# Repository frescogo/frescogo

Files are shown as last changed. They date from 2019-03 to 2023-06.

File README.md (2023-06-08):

<meta http-equiv="Content-Type" content="text/html; charset=UTF-8"/>

# FrescoGO! (v5)

O *FrescoGO!* é um software para avaliação de apresentações de Frescobol
competitivo.
A avaliação é baseada na velocidade que a bolinha atinge a cada golpe dos
atletas.
O *FrescoGO!* oferece dois modos de aferição das velocidades:
- Automático com um radar Doppler que mede as velocidades de pico da bolinha
  continuamente.
- Manual com teclas que medem o intervalo de tempo entre dois golpes
  consecutivos para inferir as velocidades considerando uma distância
  predeterminada entre os atletas.

Links do projeto:
- Site: <https://github.com/frescogo/frescogo>
- E-mail: <go.frescobol@gmail.com>
- Licença: <https://creativecommons.org/publicdomain/mark/1.0/deed.pt_BR>

**O software e a regra do FrescoGO! são de domínio público, podendo ser usados,
  copiados e modificados livremente.**

## Regra

<!--
![Tabela de Pontuação de Golpes](bonus.png)
-->

<p>
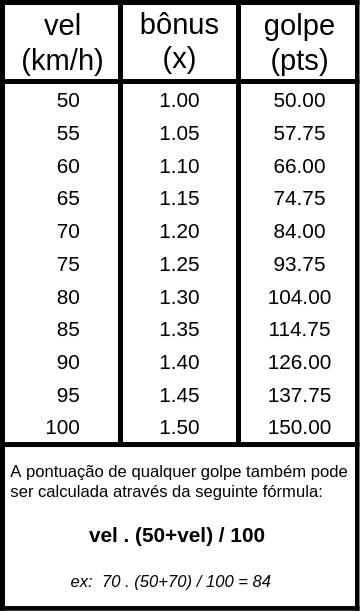
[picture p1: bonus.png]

</p>

- **Tempo**:
    - 6 minutos cronometrados.
- **Quedas**:
   - Cada queda subtrai 12 segundos do tempo corrente.
- **Equilíbrio**:
    - A diferença de pontuação entre os atletas fica limitada a até 30%.
      (Se um atleta pontua 10000, então o outro fica limitado a até 13000.)
- **Golpes**:
   - *Simples*:
        - Cada golpe simples pontua de acordo com a tabela ao lado.
        - São considerados somente os 150 golpes mais fortes de cada atleta.
   - *Contínuos (opcional)*:
        - A cada 10 golpes contínuos, o 5o mais forte deles pontua em dobro.
        - Um golpe contínuo deve suceder em até 1,5 segundo o golpe imediatamente anterior dado do mesmo atleta.
    - *Potentes (opcional)*:
        - Os 25 golpes mais potentes de forehand e de backhand de cada atleta são pontuados em dobro.
        - Um golpe potente deve ser 20% mais forte que o golpe imediatamente anterior.

<!--
- Cada atleta é avaliado em separado com uma pontuação:
    - `ATL = Ata x Vel`
        - `ATL` é a pontuação do atleta a ser calculada.
        - `Ata` é a quantidade de ataques.
        - `Vel` é a média de velocidade dos golpes.
    - São validados somente os `100` ataques mais fortes acima de `50` km/h.
- Cada queda desconta `2%` da pontuação da dupla:
    - `TOTAL = (ATL1 + ATL2) - (2% por queda)`
    - A apresentação é encerrada sumariamente ao atingir `16` quedas.
- Em caso de empate entre duplas, os seguintes quesitos serão usados para
  desempate:
    (1) maior quantidade de golpes,
    (2) menor quantidade de quedas,
    (3) sorteio.
- Resumo:
```
    ATL1  = Ata x Vel
    ATL2  = Ata x Vel
    TOTAL = (ATL1 + ATL2) - (2% por queda)
```
-->

## Agradecimentos

Agradecemos a todos os que contribuíram para o desenvolvimento do FrescoGO!:

- Adão (RJ)
- Alessandra (BA)
- Antônio (RJ)
- Clebinho (RN)
- Dão (RJ)
- Elton (RJ)
- Fátima (RJ)
- Lúcia (RJ)
- Luciano Paredão (RN)
- Luiz Negão (RJ)
- Mateus (RJ)
- PH (RJ)
- Wal (RJ)

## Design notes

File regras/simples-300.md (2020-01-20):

<!--
pandoc simples-300.md -H deeplists.tex -o /tmp/x.pdf
pdftoppm /tmp/x.pdf /tmp/x -png
convert /tmp/x-1.png -trim /tmp/x.png
convert /tmp/x.png -bordercolor White -border 8 simples-300.png
eog simples-300.png
-->

\pagenumbering{gobble}

## FrescoGO! - Regra para 5:00 minutos

Cada atleta é avaliado individualmente em três médias de velocidade:

- Volume:
    média de velocidade de todos os golpes (ataques ou defesas).
- Máximas:
    - Normal:
        média de velocidade dos `24` golpes mais fortes.
    - Revés:
        média de velocidade dos `16` golpes mais fortes de revés.
        - Esse quesito é opcional e pode ser desabilitado.

As três médias constituem a nota de cada atleta com os seguintes pesos:

- `60%` Volume, `25%` Normal, `15%` Revés (quando o revés está habilitado)
- `75%` Volume, `25%` Normal, `0%` Revés (quando o revés está desabilitado)

A pontuação final da dupla será a média entre as notas dos dois atletas.

Caso a nota de um dos atletas esteja muito abaixo da média (margem de `5%`),
então a pontuação final da dupla será essa menor nota.

Cada queda ainda desconta `1%` da pontuação final.
Com 20 quedas, a apresentação é encerrada.

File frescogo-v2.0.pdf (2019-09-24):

## FrescoGO! (versão 2.0)

FrescoGO! é um marcador eletrônico semiautomático para treinamento e competições de Frescobol.

O aparelho marcador contém dois botões de marcação: um para o atleta à esquerda e um para o atleta à direita. A marcação é feita por um juiz, que pressiona o botão correspondente ao atleta toda vez que ele acerta a bola. Com base em uma distância previamente estabelecida e o tempo decorrido entre dois golpes consecutivos, o aparelho calcula a velocidade média atingida pela bola a cada troca. O botão do meio sinaliza início de sequência, queda de bola, fim de apresentação, etc. Também há uma entrada USB para visualização do placar e um saída para som para sinalizar os golpes.

Figure 1: Foto do marcador

- Links do projeto:
- Site: https://github.com/frescogo/frescogo
- E-mail: go.frescobol@gmail.com
- Vídeos: https://www.youtube.com/channel/UCrc_Ds56Bh77CFKXldIU-9g (https://www.youtube.com/channel/UCrc_Ds56Bh77CFKXldIU-9g)
- Licença: https://creativecommons.org/publicdomain/mark/1.0/deed.pt_BR (https://creativecommons.org/publicdomain/mark/1.0/deed.pt_BR)

O projeto eletrônico, o software e a regra são de domínio público, podendo ser usados, copiados e modificados livremente.

Regra de Pontuação

Configuração considerada:

- Tempo: 300s cronometrados (5 minutos)

Quesitos de pontuação:

1

- Atleta:
- Cada atleta é avaliado individualmente pelos seguintes quesitos:
- Volume:
- Média quadrática da velocidade de todos os seus golpes.
- (A média usa as velocidades elevadas ao quadrado.)
- Máximas - Normal:
- Média simples da velocidade dos 24 golpes mais fortes pelo seu lado preferencial (“lado normal”).
- Máximas - Revés:
- Média simples da velocidade dos 12 golpes mais fortes pelo seu lado preferencial (“lado normal”).
- O total do atleta é a média ponderada dos três quesitos:
- ATLETA = (7x Volume + 2x Normal + 1x Revez) / 10
- Equilíbrio:
- A pontuação da dupla será a média de pontos entre os dois atletas.
- Se o atleta que pontuou menos estiver muito abaixo dessa média, então a pontuação da dupla será baseada no menor valor.
- O total da dupla é o menor valor entre a média dos dois e 110% do que pontuou menos:
- EQUILIBRIO = MIN( (A1+A2)/2, MIN(A1,A2)x1.1 )
- Continuidade:
- A apresentação é encerrada sumariamente na 20a queda.
- Os dois últimos golpes antes de cada queda são desconsiderados.
- Cada queda subtrai 2% da pontuação de equilíbrio da dupla:
- TOTAL = EQUILIBRIO x (100 - 2xQUEDAS) / 100

Fluxo da Apresentação

- Um som agudo longo indica que a uma nova apresentação irá começar.
- Um som agudo indica que o atleta pode sacar.
- Após o saque, o juiz pressiona o botão correspondente a cada atleta toda vez que ele acerta a bola. O tempo só passa quando o botão é pressionado.
- Um som identifica a faixa de velocidade do golpe anterior:
- < 40 kmh: som simples grave
- < 50 kmh: som simples médio
- < 60 kmh: som simples agudo
- < 70 kmh: som duplo grave
- < 80 kmh: som duplo médio
- < 90 kmh: som duplo agudo
- >= 90 kmh: som duplo muito agudo
- Um golpe do lado não preferencial do atleta acompanha um som grave (após o som correspondente à velocidade).

2

- Quando a apresentação está desequilibrada, os ataques do atleta que mais pontuou acompanham um som grave.
- Quando a bola cai, o juiz pressiona o botão de queda que emite um som característico.
- Os dois últimos golpes são ignorados e o tempo volta ao momento do último golpe considerado (i.e., um ataque tem que ser defendido e depois confirmado pelo próprio atacante).
- O juiz então pressiona o botão que habilita o saque e o fluxo reinicia.
- Um som agudo é emitido a cada 1 minuto e também quando faltam 30, 10, e 5 segundos para a apresentação terminar.
- A apresentação termina após 5 minutos cronometrados ou após a 20a queda. Um som grave longo indica que a apresentação terminou.
- Ao fim da apresentação, é gerado um relatório com todas as medições de golpes.

Formatação do Resultado

A seguir são explicados os formatos de exibição do resultado da apresentação.

- Placar (a cada sequência)
| Joao / Maria | <-- nome dos atletas
TOTAL | 41.73 pts | <-- total de pontos
Tempo Restante ..... 01:23 | <-- tempo restante
Quedas | 10 | <-- número de quedas
Golpes | 440 | <-- quantidade de golpes
Média | 51 kmh | <-- média geral em km/h
Juiz | Arnaldo | <-- nome do juiz

Joao: 50.27 pts (50.70 vol / 63.87 nrm / 20.08 rev) <-- totais do atleta à esquerda
rev | [ 45 44 40 39 38 35 00 00 00 00 00 00 ... ] | <-- 24 golpes de revés mais fortes
nrm | [ 75 69 67 65 65 65 65 64 64 64 64 64 ... ] | <-- 24 golpes normais | mais fortes

Maria: 54.07 pts (53.39 vol / 64.20 nrm / 38.66 rev) <-- totais do atleta à direita
rev | [ 48 46 41 40 38 38 36 36 36 35 35 35 ... ] | <-- 24 golpes de revés mais fortes
nrm | [ 71 71 67 65 65 64 64 64 64 64 64 64 ... ] | <-- 24 golpes normais | mais fortes

3

v200/750cm/300s/maxs(85,200)/equ1/cont20/fim20) | <-- configurações
\-- versão do software
\-- distância entre os ateltas
\-- tempo máximo de apresentação \-- velocidade máxima a detectar (85 km/h) \-- sensibilidade do revés (200ms)
\-- quesito de equilíbrio (0=desligado, 1=ligado) \-- desconto por queda (20 = 2.0%)
\-- número máximo de quedas

- Relatório (ao final da apresentação)
-- Sequencia | 1 ---------------- | <-- Início da primeira sequência.
**** | <-- Maria efetuou o primeiro golpe.
800 | (33 km/h) | <-- Joao golpeou 800ms depois.
440 | (61 km/h) | A velocidade do primeiro golpe de
820 | (32 km/h) | Maria foi de 33 km/h.
350 | (77 km/h)
790 | (34 km/h)
930 ! | (29 km/h) | <-- Joao golpeou de esquerda (!).
550 | (49 km/h) | <-- Maria golpeou 550ms depois.
610 | (44 km/h) | A velocidade do golpe anterior de
820 | (32 km/h) | Joao foi de 44 km/h.
360 | (75 km/h)
700 | (38 km/h)
370
<-- Queda.
-- Sequencia XX ---------------- | <-- Outras sequências...

Atleta | | | Vol | Nrm | Rev | | | Total | <-- Volume, Normal, Revés e Total
Joao | | | 50.70 | 63.87 | 20.08 | | | 50.27 pts | <-- Pontuação de Joao
Maria | | | 53.39 | 64.20 | 38.66 | | | 54.07 pts | <-- Pontuação de Maria

Media | 52.17 pts | <-- Média entre Joao e Maria
Equilibrio ...... 00.00 (-) | <-- Desconto de equilíbrio
Quedas (10) ..... | 20% (-) | <-- Desconto de quedas
TOTAL | 41.73 pts | <-- Pontuação final da dupla

4

Instruções para o Juiz

Ligação dos Cabos

- Celular (micro USB) -> Aparelho (mini USB)
- É necessário um adaptador micro USB para USB
- Aparelho (PS2/AUX) -> Som (PS2/AUX)

Aparelho marcador:

- Nova apresentação:
- Pressione o botão do meio e em seguida o da direita por 3 segundos.
- Resposta: um som médio de dois segundos.
- Início de sequência:
- Pressione o botão do meio por um segundo, até escutar um som.
- Resposta: um som agudo de meio segundo.
- Golpes dos atletas:
- Pressione o botão da esquerda ou direita quando, respectivamente, o atleta à esquerda ou à direita golpearem a bola. Se o golpe for um revés (lado não preferencial do atleta), o pressionamento deve ser um pouco mais demorado.
- Resposta: depende da velocidade (ver a seção “Fluxo da Apresentação”).
- Queda de bola:
- Pressione o botão do meio por um segundo, até escutar um som.
- Resposta: três sons cada vez mais graves por meio segundo.
- Fim da apresentação:
- Automático, quando o tempo do cronômetro expirar.
- Resposta: um som grave por dois segundos.
- Desfazer última sequência:
- Pressione o botão do meio e em seguida o da esquerda por 3 segundos.
- Resposta: três sons cada vez mais agudos por meio segundo.
- Reconfiguração de fábrica:
- Pressione o botão do meio e em seguida os da esquerda e direita por 3 segundos.
- Resposta: um som médio de dois segundos.
- Em | princípio, | esse | procedimento | nunca | deverá | ser
necessário.

Aplicativo Android

- Instalação (apenas uma vez):
- Instalar o app Serial USB Terminal (by Kai Morich).

5

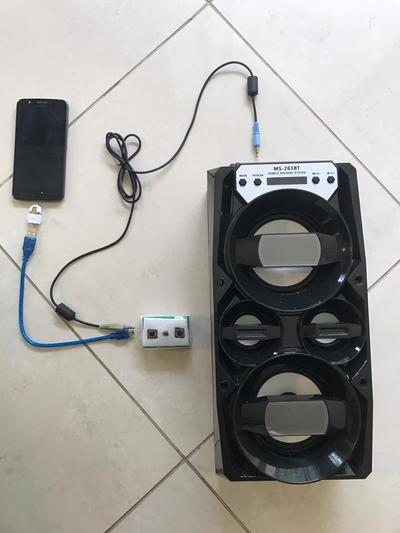
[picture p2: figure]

Figure 2: Ligação dos Cabos

6

- https://play.google.com/store/apps/details?id=de.kai_morich.serial_usb_terminal (https://play.google.com/store/apps/details?id=de.kai_morich.serial_usb_terminal)
- Configuração (apenas uma vez):
- Tocar nas três barras paralelas no canto superior esquerdo e selecionar Settings.
- Trocar Baud rate para 9600.
- Trocar Font size para 10.
- Trocar Font style para Monospace.
- Desabilitar Show timestamps.
- Trocar Buffer size para Unlimited.
- Habilitar Clear input on send.
- Habilitar Keep screen on when connected.

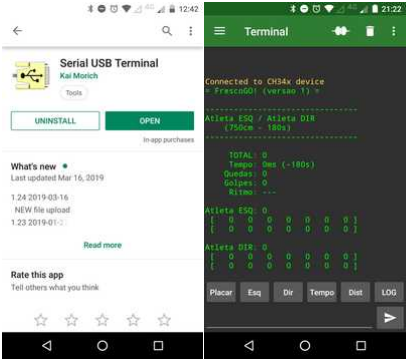
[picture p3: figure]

7

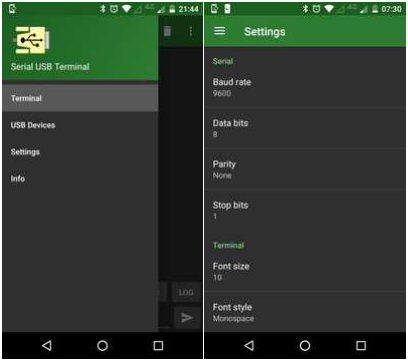
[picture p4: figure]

8

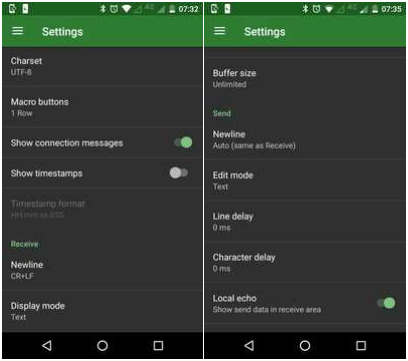
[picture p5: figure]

9

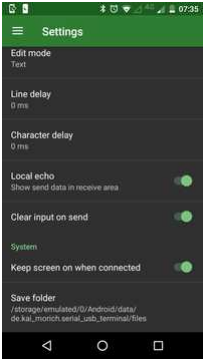
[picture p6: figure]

- Conexão (sempre que abrir o aplicativo):
- Conectar o aparelho ao celular via cabo USB.
- Tocar no ícone com dois cabos desconectados no centro superior direito da tela.
- O ícone deve mudar para um com cabos conectados.
- A área central do app deve exibir Connected to... e o placar da última apresentação.
- Comandos (durante as apresentações):
- Digitar o comando completo na área de texto na base inferior e em seguida tocar no ícone com uma seta no canto inferior direito.
- Exibição:
- placar
- exibe o placar da apresentação
- relatorio
- exibe o relatório completo da apresentação

10

- Ação:
- reiniciar
- reinicia a apresentação imediatamente
- terminar
- termina a apresentação imediatamente
- desfazer
- desconsidera por inteiro a sequência anterior
- restaurar
- restaura a configuração de fábrica
- Configuração da Apresentação:
- tempo SEGS
- altera o tempo total das apresentações para SEGS, que deve ser um número em segundos
- Exemplo:
- tempo 180
- altera o tempo de apresentação para 3 minutos
- distancia CMS
- altera a distância das apresentações para CMS, que deve ser um número em centímetros
- Exemplo:
- distancia 800
- altera a distância para 8 metros
- `maxima VEL`
- altera a velocidade máxima a ser considerada para `VEL`, que deve ser um número em kmh (bolas acima de `VEL` serão consideradas como `VEL`)
- Exemplo:
- `maxima 90`
- bolas acima de 90 kmh serão interpretadas como 90 kmh
- `reves MS`
- altera o tempo mínimo para detectar um revés para `MS`, que deve ser um número em milisegundos
- caso o valor seja `0`, os golpes de revés serão desconsiderados
- Exemplo:
- `reves 200`
- altera a sensibilidade do revés para 200 milisegundos
- `equilibrio SIM/NAO`
- liga ou desliga a pontuação de equlíbrio (`nao=desligada`, `sim=ligada`)
- Exemplo:
- `equilibrio nao`
- desabilita a pontuação de equilibrio
- `esquerda NOME`
- altera o nome do atleta à esquerda para `NOME`, que deve ter até 15 caracteres
- Exemplo:

11

- `esquerda Maria`
- altera o nome do atleta à esquerda para *Maria*
- `direita NOME`
- altera o nome do atleta à direita para `NOME`, que deve ter até 15 caracteres
- Exemplo:
- `direita Joao`
- altera o nome do atleta à direita para *Joao*
- Configuração do Aparelho:
- `juiz NOME`
- altera o nome do juiz para `NOME`, que deve ter até 15 caracteres
- Exemplo:
- `juiz Arnaldo`
- altera o nome do juiz para *Arnaldo*
- `modo MODO`
- altera o modo de exibição para `MODO`, que deve ser `cel` ou `pc`
- Exemplo:
- `modo pc`
- altera o modo de exibição para `pc`
- Envio de relatórios:
- No aplicativo Serial USB Terminal:
- Aguarde o término da apresentação
- Aperte na lata de lixo no canto superior direito para apagar a tela
- Digite relatorio
- Aguarde o término da operação
- Aperte nos 3 pontinhos no canto superior direito
- Selecione Save Data
- Vai aparecer uma mensagem tal como Saved serial_20190602_160522.txt
- No WhatsApp:
- Selecione o contato a enviar o relatório
- Aperte no clipe para anexar um arquivo
- Selecione Documento
- Aperte em Procurar outros documentos...
- Aperte nos 3 pontinhos no canto superior direito
- Selecione Mostrar armazenamento interno
- (Esse procedimento só é necessário uma vez)
- Aperte nas 3 barrinhas no canto superior esquerdo
- Selecione o modelo do seu celular, ex.: Moto E(4)
- Selecione Android
- Selecione data
- Selecione de.kai_morich.serial_usb_terminal
- Selecione files
- Selecione o arquivo a ser anexado, ex.: serial_20190602_160522.txt
- Selecione Enviar

12

- Confirme

Perguntas e Respostas

- Qual é o objetivo desse projeto?
- Oferecer uma maneira objetiva, simples e barata de avaliar apresentações de frescobol.
- Estar disponível no maior número de arenas de frescobol que for possível.
- Auxiliar no desenvolvimento técnico de atletas, estimular a formação de novos atletas e contribuir para o crescimento do Frescobol de competição.
- Como eu consigo um aparelho desses?
- Entre em contato conosco por e-mail:
- go.frescobol@gmail.com
- Esse aparelho é um radar? Como o aparelho mede a velocidade da bola?
- O aparelho não é um radar e mede a velocidade de maneira aproximada:
- Os atletas devem estar a uma distância fixa predeterminada.
- O juiz deve pressionar o botão no momento exato dos golpes (ou o mais próximo possível).
- O aparelho divide a distância pelo tempo entre dois golpes consecutivos para calcular a velocidade.
- Exemplo: se os atletas estão a 8 metros de distância e em um momento a bola leva 1 segundo para se deslocar entre os dois, então a velocidade foi de 8m/s (29 kmh).
- Quais as desvantagens em relação ao radar?
- A principal desvantagem é que a medição não é tão precisa pois os atletas se movimentam e o juiz inevitavelmente irá atrasar ou adiantar as medições.
- OBS.: O radar também não é perfeito, tendo erro estimado entre +1/-2 kmh. Além disso, qualquer angulação entre a trajetória da bola e a posição do radar afeta negativamente as medições (ex., um ângulo de 25 graus diminui as medições em 10%).
- Fonte: https://www.stalkerradar.com/stalker-speed-sensor/faq/stalker-speed-sensor-FAQ.shtml (https://www.stalkerradar.com/stalker-speed-sensor/faq/stalker-speed-sensor-FAQ.shtml)
- Tem alguma vantagem em relação ao radar?
- Custo: Os componentes do aparelho somados custam menos de R$50. O radar custa em torno de US$1000 e não inclui o software para frescobol.
- Licença de uso: Além do custo ser menor, não há nenhuma restrição legal sobre o uso do aparelho, software ou regra por terceiros.
- Infraestrutura: Além do aparelho, é necessário apenas um celular

13 com um software gratuito (para obter o placar das apresentações) e uma caixa de som potente (de preferência com bateria interna). Não é necessário computador, ponto de luz elétrica, área protegida ou outros ajustes finos para a medição da apresentação. Essa simplicidade permite que múltiplas arenas funcionem ao mesmo tempo.
- Transparência das medições: Apesar de serem menos precisas, as medições são audíveis e qualquer erro grosseiro pode ser notado imediatamente. O radar só mede bolas acima de 40 kmh e não é possível identificar se as medições estão sempre corretas (o posicionamento dos atletas, vento e outros fatores externos podem afetar as medições).
- Verificabilidade das medições: Os atletas podem verificar/auditar se a pontuação final foi justa. As apresentações podem ser medidas por um aparelho igual durante as apresentaçõs ou podem ser gravados para medição posterior pelo vídeo.
- Eu posso usar o marcador em competições? Quanto custa? A quem devo pedir permissão?
- Não há nenhuma restrição de uso.
- Não há custos.
- Não é necessário pedir autorização. Não é nem mesmo necessário mencionar o nome do sistema ou autores.
- Como eu posso contribuir?
- Adotando o sistema no dia a dia da sua arena.
- Principalmente com atletas iniciantes.
- Promovendo competições.
- Produzindo vídeos.
- Enviando os relatórios das apresentações para nós.
- Por quê as velocidades são elevadas ao quadrado no quesito de Volume?
- Para incentivar os golpes mais potentes. Quanto maior a velocidade, maior ainda será o quadrado dela. Um golpe a 100 km/h é 2 vezes mais rápido que um a 50 km/h, mas o quadrado de 100 km/h é 4 vezes maior que o de 50 km/h (10000 vs 2500).
- Qual é o objetivo do quesito de Máximas?
- Bonificando os 36 golpes mais velozes pelos dois lados do atleta (12 de revés e 24 normais), a regra incentiva que o atleta ataque acima do seu limite. Os 36 golpes correspondem a mais ou menos 15% dos ataques de um atleta em uma apresentação de 5 minutos.
- Tem como o juiz “roubar”?
- Ao atrasar a marcação de um golpe “A”, consequentemente o golpe “B” seguinte será adiantado. O golpe “A” terá a velocidade reduzida e o golpe “B” terá a velocidade aumentada. Como a regra usa o quadrado das velocidades, esse atraso e adiantamento (se forem sistemáticos) podem afetar a pontuação final.
- Tem como o atleta “roubar” ou “tirar vantagem” da regra?

14

- O atleta pode projetar o corpo para frente e adiantar ao máximo os golpes para aumentar a medição das velocidades.

15

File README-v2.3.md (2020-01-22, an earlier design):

<meta http-equiv="Content-Type" content="text/html; charset=UTF-8"/>

<!--
$ pandoc README.md -H deeplists.tex -o frescogo.pdf
$ pandoc README.md -H deeplists.tex -o frescogo.html
-->

# FrescoGO! (versão 2.3)

*FrescoGO!* é um marcador eletrônico semiautomático para treinamento e
competições de Frescobol.

O aparelho marcador contém dois botões de marcação: um para o atleta à esquerda
e um para o atleta à direita.
A marcação é feita por um juiz, que pressiona o botão correspondente ao atleta
toda vez que ele acerta a bola.
<!--
Golpes de esquerda e direita são distinguidos pelo tempo de pressionamento do
botão.
-->
Com base em uma distância previamente estabelecida e o tempo decorrido entre
dois golpes consecutivos, o aparelho calcula a velocidade média atingida pela
bola a cada troca.
O botão do meio sinaliza início de sequência, queda de bola, fim de
apresentação, etc.
Também há uma entrada USB para visualização do placar e um saída para som para
sinalizar os golpes.

Foto do marcador Foto do Aparelho

- Links do projeto:
    - Site: <https://github.com/frescogo/frescogo>
    - E-mail: <go.frescobol@gmail.com>
    - Vídeos: <https://www.youtube.com/channel/UCrc_Ds56Bh77CFKXldIU-9g>
    - Licença: <https://creativecommons.org/publicdomain/mark/1.0/deed.pt_BR>

**O projeto eletrônico, o software e a regra são de domínio público, podendo
ser usados, copiados e modificados livremente.**

-------------------------------------------------------------------------------

## Regra para 5:00 minutos

- **Golpes:**
    - Cada atleta é avaliado individualmente pelas médias de velocidade dos
      seguintes quesitos:
        - **Volume:**
            - Média *quadrática* da velocidade de todos os seus golpes.
                - (A média quadrática considera as velocidades elevadas ao
                   quadrado.)
        - **Máximas - Normal:**
            - Média simples da velocidade dos `24` golpes mais fortes efetuados
              pelo seu lado preferencial ("lado normal").
        - **Máximas - Revés:**
            - Esse quesito é opcional e pode ser desabilitado.
            - Média simples da velocidade dos `16` golpes mais fortes efetuados
              pelo seu lado não preferencial ("lado revés").
            - O revés só é válido quando supera em 10% a velocidade do golpe
              anterior do parceiro.
    - O total do atleta é a média ponderada entre os quesitos.
        - Revés habilitado:
            - `ATLETA = 60% Volume + 25% Normal + 15% Revés`
        - Revés desabilitado:
            - `ATLETA = 75% Volume + 25% Normal`
- **Equilíbrio:**
    - A pontuação de equilíbrio da dupla é a média entre os totais dos dois
      atletas.
    - Se um atleta estiver abaixo dessa média (com uma margem de 5%), então a
      pontuação de equilíbrio será o menor total:
        - `EQUILIB = MENOR((ATL1+ATL2)/2, MENOR(ATL1,ATL2)x1.05)`
- **Continuidade:**
    - A apresentação é encerrada sumariamente na `20a` queda.
    - Os dois últimos golpes antes de cada queda são sempre desconsiderados.
    - Cada queda subtrai `1%` da pontuação após calcular o equilíbrio da dupla:
        - `FINAL = EQUILIB x (100 - 1x QUEDAS) / 100`

```
  ATLETA  = 60% Volume + 25% Normal + 15% Revés     (75% Volume com o Revés desabilitado)
  EQUILIB = MENOR( (ATLETA1+ATLETA2)/2, MENOR(ATLETA1,ATLETA2)x1.05 )
  FINAL   = EQUILIB x (100 - 1x QUEDAS) / 100
```

Em caso de empate entre duplas, os seguintes quesitos serão usados para
desempate: (1) menor quantidade de quedas, (2) maior quantidade de golpes, (3)
sorteio.

<!--
- 
      Exemplo:
        - Com 5 quedas, a dupla perderá 10% dos pontos, ou seja, se ela pontuou
          4400 após o equilíbrio, a pontuação final será de **3960 pontos**
          (`4400x90%`).
        - Ex., se os atletas pontuaram 4000 e 5000 pontos, pega-se a média
          (`(5000+4000)/2 = 4500`) e 110% do menor (`4000x110% = 4400`).
          A pontuação de equilíbrio será o menor entre os dois valores
          (`4500 vs 4400`): **4400 pontos**.

Os três quesitos são somados As três médias são 

    - A velocidade de cada golpe efetuado por um atleta é elevada ao quadrado,
      dividida por 100 e somada ao total do atleta. Não há velocidade mínima.
      Exemplos:
        - 30 kmh vale **09 pontos**: `30x30/100 =  900/100 =  9`.
        - 40 kmh vale **16 pontos**: `40x40/100 = 1600/100 = 16`.
        - 50 kmh vale **25 pontos**: `50x50/100 = 2500/100 = 25`.
        - 60 kmh vale **36 pontos**: `60x60/100 = 3600/100 = 36`.
        - 70 kmh vale **49 pontos**: `70x70/100 = 4900/100 = 49`.
        - 80 kmh vale **64 pontos**: `80x80/100 = 6400/100 = 64`.
        - 90 kmh vale **81 pontos**: `90x90/100 = 8100/100 = 81`.
- **Máximas:**
    - A média de pontuação dos `36` golpes mais velozes de cada atleta é
      multiplicada por `72` e somada ao seu total (bônus `x2` por cada golpe).
    - São considerados `24` golpes efetuados pelo lado preferencial do atleta
      ("lado normal") e `12` golpes efetuados pelo lado não preferencial do
      atleta ("lado revés").
    - Exemplo:
        - A média dos `24` golpes mais velozes do lado normal foi de `75 kmh`.
        - A média dos `12` golpes mais velozes do lado revés  foi de `55 kmh`.
        - A média dos `36` golpes mais velozes foi então de `68 kmh` com `46`
          pontos por golpe.
        - Esse atleta vai então obter **3312 pontos** (`46 x 72`) no quesito
          de *Máximas* que ainda serão somados aos seus pontos de *Volume*.
    - OBS.:
        - Tipicamente, golpes pelo lado normal são efetuados de *forehand* e
          golpes pelo lado revés de *backhand*. No entanto, qualquer qualidade
          de golpe é válida, inclusive trocando a raquete de mão.
        - Os `36` golpes dentre as máximas também são considerados no quesito
          **Volume** normalmente.
    - OBS.: Em uma apresentação de 3 minutos, 7 golpes correspondem a
      aproximadamente 10% dos golpes em posição de ataque.
-->

-------------------------------------------------------------------------------

## Fluxo da Apresentação

- Um som agudo longo indica que a uma nova apresentação irá começar.
- Um som agudo indica que o atleta pode sacar.
- Após o saque, o juiz pressiona o botão correspondente a cada atleta toda vez
  que ele acerta a bola. O tempo só passa quando o botão é pressionado.
- Um som identifica a faixa de velocidade do golpe anterior:
    - ` < 40 kmh`: som simples grave
    - ` < 50 kmh`: som simples médio
    - ` < 60 kmh`: som simples agudo
    - ` < 70 kmh`: som duplo   grave
    - ` < 80 kmh`: som duplo   médio
    - ` < 90 kmh`: som duplo   agudo
    - `>= 90 kmh`: som duplo   muito agudo
- Um golpe do lado não preferencial do atleta acompanha um som grave (após o
  som correspondente à velocidade).
- Quando a apresentação está desequilibrada, os ataques do atleta que mais
  pontuou acompanham um som grave.
- Quando a bola cai, o juiz pressiona o botão de queda que emite um som
  característico.
- Os dois últimos golpes são ignorados e o tempo volta ao momento do último
  golpe considerado (i.e., um ataque tem que ser defendido e depois confirmado
  pelo próprio atacante).
- O juiz então pressiona o botão que habilita o saque e o fluxo reinicia.
- Um som agudo é emitido a cada 1 minuto e também quando faltam 30, 10, e 5
  segundos para a apresentação terminar.
- A apresentação termina após 5 minutos cronometrados ou após o limite de
  quedas ou após aproximadamente 650 golpes (por restrições técnicas).
  Um som grave longo indica que a apresentação terminou.
- Ao fim da apresentação, é gerado um relatório com todas as medições de
  golpes.

### Formatação do Resultado

A seguir são explicados os formatos de exibição do resultado da apresentação.

- Placar (a cada sequência)

```
-----------------------------------------------
                  Joao / Maria                            <-- nome dos atletas
-----------------------------------------------

TOTAL .............. 41.73 pts                            <-- total de pontos
Tempo Restante ..... 01:23                                <-- tempo restante
Quedas ............. 10                                   <-- número de quedas
Golpes ............. 440                                  <-- quantidade de golpes
Média .............. 51 kmh                               <-- média geral em km/h
Juiz ............... Arnaldo                              <-- nome do juiz

-----------------------------------------------

      Joao: 50.27 pts (50.70 vol / 63.87 nrm / 20.08 rev) <-- totais do atleta à esquerda
 rev  [ 45 44 40 39 38 35 00 00 00 00 00 00 ... ]         <-- 24 golpes de revés mais fortes
 nrm  [ 75 69 67 65 65 65 65 64 64 64 64 64 ... ]         <-- 24 golpes normais  mais fortes

-----------------------------------------------

     Maria: 54.07 pts (53.39 vol / 64.20 nrm / 38.66 rev) <-- totais do atleta à direita
 rev  [ 48 46 41 40 38 38 36 36 36 35 35 35 ... ]         <-- 24 golpes de revés mais fortes
 nrm  [ 71 71 67 65 65 64 64 64 64 64 64 64 ... ]         <-- 24 golpes normais  mais fortes

-----------------------------------------------

v200/750cm/300s/maxs(85,200)/equ1/cont10/fim20)           <-- configurações
  \-- versão do software
       \-- distância entre os ateltas
            \-- tempo máximo de apresentação
                      \-- velocidade máxima a detectar (85 km/h)
                         \-- sensibilidade do revés (200ms)
                              \-- quesito de equilíbrio (0=desligado, 1=ligado)
                                    \-- desconto por queda (10 = 1.0%)
                                           \-- número máximo de quedas

-----------------------------------------------
```

- Relatório (ao final da apresentação)

```
-- Sequencia  1 ----------------        <-- Início da primeira sequência.
            ****                        <-- Maria efetuou o primeiro golpe.
     800            (33 km/h)           <-- Joao golpeou 800ms depois.
             440    (61 km/h)               A velocidade do primeiro golpe de
     820            (32 km/h)               Maria foi de 33 km/h.
             350    (77 km/h)
     790            (34 km/h)
     ...
             930 !  (29 km/h)           <-- Joao golpeou de esquerda (!).
     550            (49 km/h)           <-- Maria golpeou 550ms depois.
             610    (44 km/h)               A velocidade do golpe anterior de
     820            (32 km/h)               Joao foi de 44 km/h.
             360    (75 km/h)
     700            (38 km/h)
             370
                                        <-- Queda.
-- Sequencia XX ----------------        <-- Outras sequências...
...

-----------------------------------------------

    Atleta   |    Vol     Nrm     Rev    |     Total      <-- Volume, Normal, Revés e Total
      Joao   |   50.70   63.87   20.08   |   50.27 pts    <-- Pontuação de Joao
     Maria   |   53.39   64.20   38.66   |   54.07 pts    <-- Pontuação de Maria

-----------------------------------------------

Media ........... 52.17 pts             <-- Média entre Joao e Maria
Equilibrio ...... 00.00 (-)             <-- Desconto de equilíbrio
Quedas (10) .....   10% (-)             <-- Desconto de quedas
TOTAL ........... 46.95 pts             <-- Pontuação final da dupla
```

-------------------------------------------------------------------------------

## Instruções para o Juiz

### Ligação dos Cabos

- Celular (micro USB) -> Aparelho (mini USB)
    - É necessário um adaptador micro USB para USB
- Aparelho (PS2/AUX) -> Som (PS2/AUX)

Ligação dos Cabos

### Aparelho marcador:

- Nova apresentação:
    - Pressione o botão do meio e em seguida o da direita por 3 segundos.
    - Resposta: um som médio de dois segundos.
- Início de sequência:
    - Pressione o botão do meio por um segundo, até escutar um som.
    - Resposta: um som agudo de meio segundo.
- Golpes dos atletas:
    - Pressione o botão da esquerda ou direita quando, respectivamente, o
      atleta à esquerda ou à direita golpearem a bola. Se o golpe for um revés
      (lado não preferencial do atleta), o pressionamento deve ser um pouco
      mais demorado.
    - Resposta: depende da velocidade (ver a seção "Fluxo da Apresentação").
- Queda de bola:
    - Pressione o botão do meio por um segundo, até escutar um som.
    - Resposta: três sons cada vez mais graves por meio segundo.
- Fim da apresentação:
    - Automático, quando o tempo do cronômetro expirar. <!-- ou após a 25a queda. -->
    - Resposta: um som grave por dois segundos.
- Desfazer última sequência:
    - Pressione o botão do meio e em seguida o da esquerda por 3 segundos.
    - Resposta: três sons cada vez mais agudos por meio segundo.
- Reconfiguração de fábrica:
    - Pressione o botão do meio e em seguida os da esquerda e direita por
      3 segundos.
    - Resposta: um som médio de dois segundos.
    - **Em princípio, esse procedimento nunca deverá ser necessário.**

### Aplicativo Android

- Instalação (apenas uma vez):
    - Instalar o app `Serial USB Terminal` (by Kai Morich).
        - <https://play.google.com/store/apps/details?id=de.kai_morich.serial_usb_terminal>

- Configuração (apenas uma vez):
    - Tocar nas três barras paralelas no canto superior esquerdo e selecionar
      `Settings`.
    - Trocar `Baud rate` para `9600`.
    - Trocar `Font size` para `10`.
    - Trocar `Font style` para `Monospace`.
    - Desabilitar `Show timestamps`.
    - Trocar `Buffer size` para `Unlimited`.
    - Habilitar `Clear input on send`.
    - Habilitar `Keep screen on when connected`.

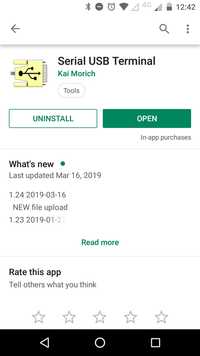
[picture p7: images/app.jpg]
Android App

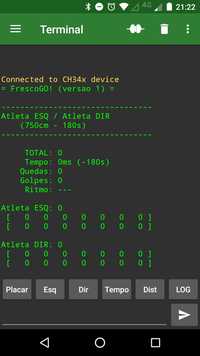
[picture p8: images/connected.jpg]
Conexão USB

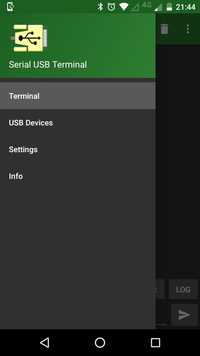
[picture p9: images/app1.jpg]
Configurações Configurações 1/5

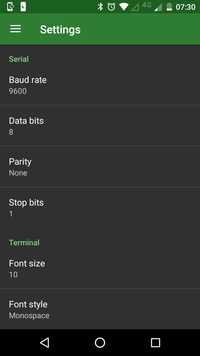
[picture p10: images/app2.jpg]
Configurações Configurações 2/5

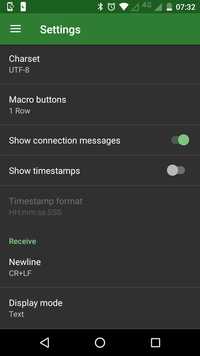
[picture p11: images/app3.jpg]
Configurações Configurações 3/5

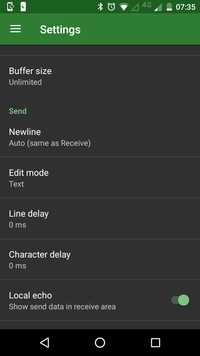
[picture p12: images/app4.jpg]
Configurações Configurações 4/5

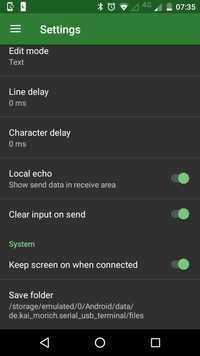
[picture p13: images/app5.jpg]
Configurações Configurações 5/5


- Conexão (sempre que abrir o aplicativo):
    - Conectar o aparelho ao celular via cabo USB.
    - Tocar no ícone com dois cabos desconectados no centro superior direito da
      tela.
        - O ícone deve mudar para um com cabos conectados.
        - A área central do app deve exibir `Connected to...` e o placar da
          última apresentação.

<!--
    - O placar da última apresentação deve ser exibido no centro da tela.
    - A cada queda e reinício, é exibido o placar da apresentação em andamento.
-->

- Comandos (durante as apresentações):
    - Digitar o comando completo na área de texto na base inferior e em seguida
      tocar no ícone com uma seta no canto inferior direito.
    - Exibição:
        - `placar`
            - exibe o placar da apresentação
        - `relatorio`
            - exibe o relatório completo da apresentação
    - Ação:
        - `reiniciar`
            - reinicia a apresentação imediatamente
        - `terminar`
            - termina a apresentação imediatamente
        - `desfazer`
            - desconsidera por inteiro a sequência anterior
        - `restaurar`
            - restaura a configuração de fábrica
    - Configuração da Apresentação:
        - `tempo SEGS`
            - altera o tempo total das apresentações para `SEGS`, que deve ser
              um número em segundos
            - Exemplo:
                - `tempo 180`
                - altera o tempo de apresentação para 3 minutos
        - `distancia CMS`
            - altera a distância das apresentações para `CMS`, que deve ser um
              número em centímetros
            - Exemplo:
                - `distancia 800`
                - altera a distância para 8 metros

<!--
        - `maximas SIM/NAO`
            - liga ou desliga a pontuação de máximas (`nao=desligada`, `sim=ligada`)
            - Exemplo:
                - `maximas sim`
                - habilita a pontuação de máximas
-->

        - `maxima VEL`
            - altera a velocidade máxima a ser considerada para `VEL`, que deve
              ser um número em kmh (bolas acima de `VEL` serão consideradas
              como `VEL`)
            - Exemplo:
                - `maxima 90`
                - bolas acima de 90 kmh serão interpretadas como 90 kmh
        - `reves MS`
            - altera o tempo mínimo para detectar um revés para `MS`, que deve
              ser um número em milisegundos
            - caso o valor seja `0`, os golpes de revés serão desconsiderados
            - Exemplo:
                - `reves 200`
                - altera a sensibilidade do revés para 200 milisegundos
        - `equilibrio SIM/NAO`
            - liga ou desliga a pontuação de equlíbrio (`nao=desligada`, `sim=ligada`)
            - Exemplo:
                - `equilibrio nao`
                - desabilita a pontuação de equilibrio
        - `esquerda NOME`
            - altera o nome do atleta à esquerda para `NOME`, que deve ter até
              15 caracteres
            - Exemplo:
                - `esquerda Maria`
                - altera o nome do atleta à esquerda para *Maria*
        - `direita NOME`
            - altera o nome do atleta à direita para `NOME`, que deve ter até
              15 caracteres
            - Exemplo:
                - `direita Joao`
                - altera o nome do atleta à direita para *Joao*
    - Configuração do Aparelho:
        - `juiz NOME`
            - altera o nome do juiz para `NOME`, que deve ter até 15 caracteres
            - Exemplo:
                - `juiz Arnaldo`
                - altera o nome do juiz para *Arnaldo*
        - `modo MODO`
            - altera o modo de exibição para `MODO`, que deve ser `cel` ou `pc`
            - Exemplo:
                - `modo pc`
                - altera o modo de exibição para `pc`

- Envio de relatórios:
    
    - No aplicativo `Serial USB Terminal`:
        - Aguarde o término da apresentação
        - Aperte na lata de lixo no canto superior direito para apagar a tela
        - Digite `relatorio`
            - Aguarde o término da operação
        - Aperte nos 3 pontinhos no canto superior direito
            - Selecione `Save Data`
                - Vai aparecer uma mensagem tal como `Saved serial_20190602_160522.txt`
    - No `WhatsApp`:
        - Selecione o contato a enviar o relatório
        - Aperte no clipe para anexar um arquivo
            - Selecione `Documento`
        - Aperte em `Procurar outros documentos...`
        - Aperte nos 3 pontinhos no canto superior direito
            - Selecione `Mostrar armazenamento interno`
                - (Esse procedimento só é necessário uma vez)
        - Aperte nas 3 barrinhas no canto superior esquerdo
            - Selecione o modelo do seu celular, ex.: `Moto E(4)`
            - Selecione `Android`
            - Selecione `data`
            - Selecione `de.kai_morich.serial_usb_terminal`
            - Selecione `files`
            - Selecione o arquivo a ser anexado, ex.:  `serial_20190602_160522.txt`
            - Selecione `Enviar`
                - Confirme

<!--
        - `continuidade PCT`
            - altera o percentual de perda por queda de bola para `PCT`, que
              deve ser um número
-->

-------------------------------------------------------------------------------

## Perguntas e Respostas

- Qual é o objetivo desse projeto?
    - Oferecer uma maneira objetiva, simples e barata de avaliar apresentações
      de frescobol.
    - Estar disponível no maior número de arenas de frescobol que for possível.
    - Auxiliar no desenvolvimento técnico de atletas, estimular a formação de
      novos atletas e contribuir para o crescimento do Frescobol de competição.

- Como eu consigo um aparelho desses?
    - Entre em contato conosco por e-mail:
        - <go.frescobol@gmail.com>

- Esse aparelho é um radar? Como o aparelho mede a velocidade da bola?
    - O aparelho não é um radar e mede a velocidade de maneira aproximada:
        - Os atletas devem estar a uma distância fixa predeterminada.
        - O juiz deve pressionar o botão no momento exato dos golpes (ou o mais
          próximo possível).
        - O aparelho divide a distância pelo tempo entre dois golpes
          consecutivos para calcular a velocidade.
        - Exemplo: se os atletas estão a 8 metros de distância e em um momento
          a bola leva 1 segundo para se deslocar entre os dois, então a
          velocidade foi de 8m/s (29 kmh).

- Quais as desvantagens em relação ao radar?
    - A principal desvantagem é que a medição não é tão precisa pois os atletas
      se movimentam e o juiz inevitavelmente irá atrasar ou adiantar as
      medições.
    - OBS.:
      O radar também não é perfeito, tendo erro estimado entre +1/-2 kmh.
      Além disso, qualquer angulação entre a trajetória da bola e a posição do
      radar afeta negativamente as medições (ex., um ângulo de 25 graus diminui
      as medições em 10%).
        - Fonte: <https://www.stalkerradar.com/stalker-speed-sensor/faq/stalker-speed-sensor-FAQ.shtml>

- Tem alguma vantagem em relação ao radar?
    - **Custo**:
        Os componentes do aparelho somados custam menos de R$50.
        O radar custa em torno de US$1000 e não inclui o software para
        frescobol.
    - **Licença de uso**:
        Além do custo ser menor, não há nenhuma restrição legal sobre o uso
        do aparelho, software ou regra por terceiros.
    - **Infraestrutura**:
        Além do aparelho, é necessário apenas um celular com um software
        gratuito (para obter o placar das apresentações) e uma caixa de som
        potente (de preferência com bateria interna).
        Não é necessário computador, ponto de luz elétrica, área protegida ou
        outros ajustes finos para a medição da apresentação.
        Essa simplicidade permite que múltiplas arenas funcionem ao mesmo
        tempo.
    - **Transparência das medições**:
        Apesar de serem menos precisas, as medições são audíveis e qualquer
        erro grosseiro pode ser notado imediatamente.
        O radar só mede bolas acima de 40 kmh e não é possível identificar se
        as medições estão sempre corretas (o posicionamento dos atletas, vento
        e outros fatores externos podem afetar as medições).
    - **Verificabilidade das medições**:
        Os atletas podem verificar/auditar se a pontuação final foi justa.
        As apresentações podem ser medidas por um aparelho igual durante as
        apresentaçõs ou podem ser gravados para medição posterior pelo vídeo.

- Eu posso usar o marcador em competições? Quanto custa? A quem devo pedir
  permissão?
    - Não há nenhuma restrição de uso.
    - Não há custos.
    - Não é necessário pedir autorização.
      Não é nem mesmo necessário mencionar o nome do sistema ou autores.

- Como eu posso contribuir?
    - Adotando o sistema no dia a dia da sua arena.
        - Principalmente com atletas iniciantes.
    - Promovendo competições.
    - Produzindo vídeos.
    - **Enviando os relatórios das apresentações para nós.**

<!--
- Como eu posso contribuir financeiramente?
    -
-->

-------------------------------------------------------------------------------

- Por quê as velocidades são elevadas ao quadrado no quesito de *Volume*?
    - Para incentivar os golpes mais potentes.
      Quanto maior a velocidade, maior ainda será o quadrado dela.
      Um golpe a 100 km/h é 2 vezes mais rápido que um a 50 km/h, mas o
      quadrado de 100 km/h é 4 vezes maior que o de 50 km/h (10000 vs 2500).

- Qual é o objetivo do quesito de *Máximas*?
    - Bonificando os 36 golpes mais velozes pelos dois lados do atleta (12 de
      revés e 24 normais), a regra incentiva que o atleta ataque acima do seu
      limite.
      Os 36 golpes correspondem a mais ou menos 15% dos ataques de um atleta em
      uma apresentação de 5 minutos.

<!--
    - E por quê a regra não considera todos os 7 golpes mais velozes (no lugar
      de considerar apenas o 7o)?
        - Para minimizar a imprecisão da marcação do juiz.
          É possível que o juiz acelere a marcação de alguns golpes, mas é
          pouco provável que isso afete sensivelmente a 7a bola mais veloz.

- Por quê algumas apresentações já iniciam com uma pontuação que eu não consigo
  zerar?
    - Quando a pontuação de Máximas está desligada (`potencia nao`), a regra
      assume um valor fixo de 50 kmh para todos os 7 golpes mais velozes de
      esquerda e de direita **que já são contabilizados no início da
      apresentação**.
    - Isso é feito para evitar os dois modos (ligado e desligado) fiquem com
      pontuações próximas.
-->

- Tem como o juiz "roubar"?
    - Ao atrasar a marcação de um golpe "A", consequentemente o golpe "B"
      seguinte será adiantado.
      O golpe "A" terá a velocidade reduzida e o golpe "B" terá a velocidade
      aumentada.
      Como a regra usa o quadrado das velocidades, esse atraso e adiantamento
      (se forem sistemáticos) podem afetar a pontuação final.

- Tem como o atleta "roubar" ou "tirar vantagem" da regra?
    - O atleta pode projetar o corpo para frente e adiantar ao máximo os golpes
      para aumentar a medição das velocidades.

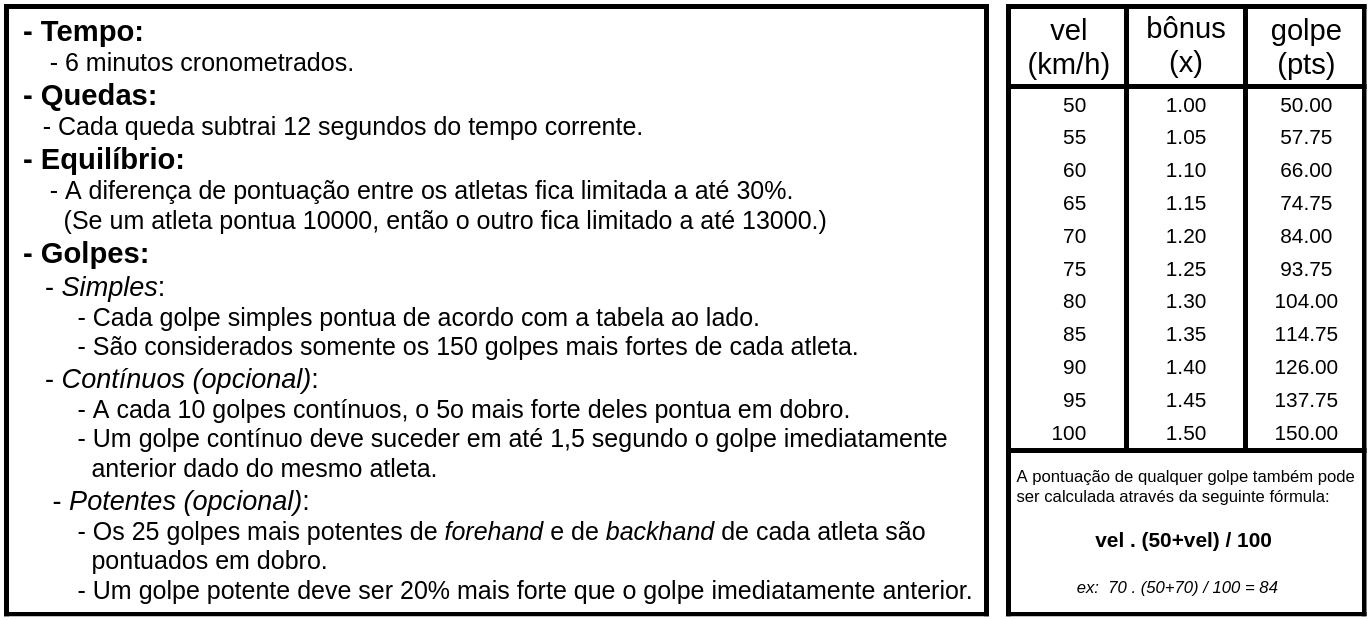
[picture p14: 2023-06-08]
regra.png

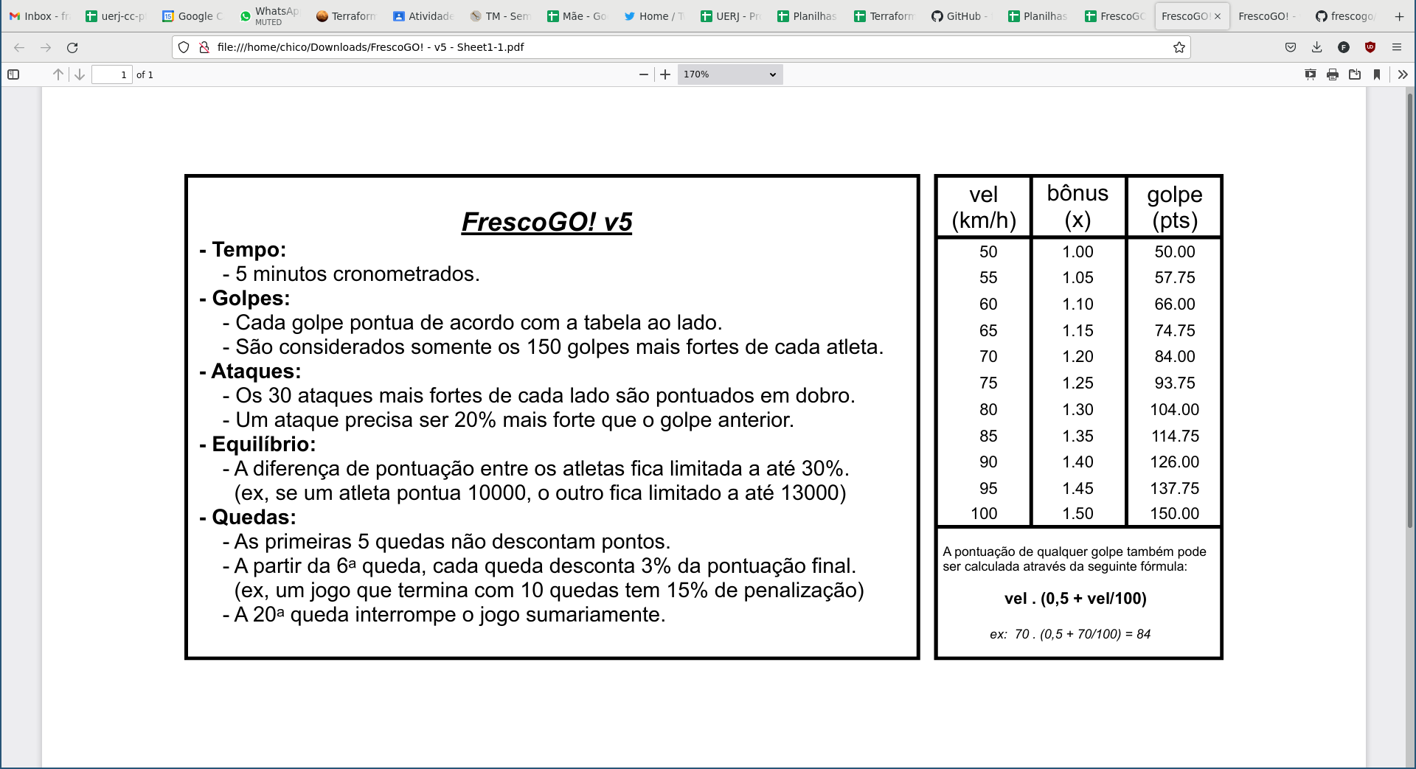
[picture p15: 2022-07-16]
frescogo.png

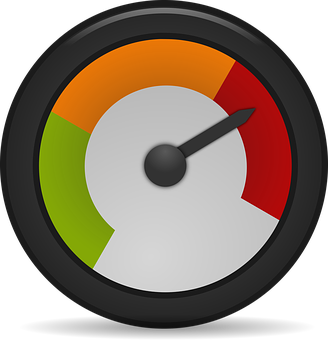
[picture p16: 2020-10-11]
slides/avericao.webp

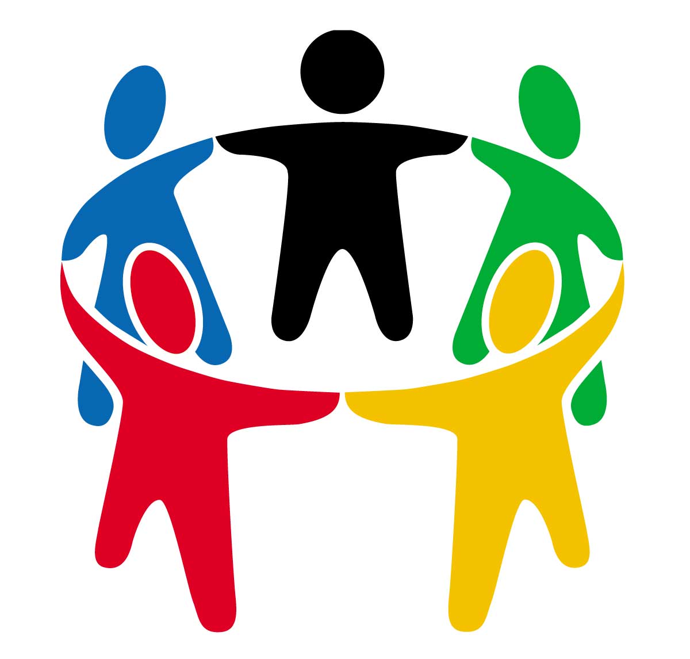
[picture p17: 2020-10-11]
slides/grupo.jpg

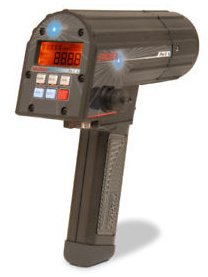
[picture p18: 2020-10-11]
slides/stalker.jpg

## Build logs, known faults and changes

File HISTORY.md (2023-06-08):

v5.4 (jun/23)
-------------

- Nova regra para quedas: remove tempo em vez de pontos.
    - Não há mais limite de 20 quedas.
- Prefixo de categoria para os logs configurável.
- Remove opção da regra v4.

v5.3 (fev/23)
-------------

- Exibe maxs/ints no placar.

v5.2 (out/22)
-------------

- Nova regra de intensidade.
- Pisca tempo a partir de `0:05`, sem decrescer até terminar.
- Renomeia regra de "Ataques" para "Máximas".

v5.1 (ago/22)
-------------

- Timer de teclas 2s para 3s.
- Alternância de regras `CTRL-V` (v4 e v5).
- Som duplo para defesa (no lugar de golpe normal).
- Teclas `Z/M` separadas para esquerda/direita e com tolerância de 500ms.

v5.0 (jul/22)
-------------

- Modo `CTRL-M` de depuração.
- Algumas operações por teclado requerem 3s de pressionamento.
- Regra de ataques dos dois lados (dir/esq).
  - Árbitro pressiona Z ou M para golpe não preferencial, que acompanha um som.
- Nova fórmula de bônus.
- Exibe médias de velocidade ao final do jogo (máx/min, 75+/75-, dir/esq).
- Exibição dos atletas não mais espelhada.
- Relatório foi simplificado.

v4.3 (jan/22)
-------------

- Nova faixa de som acima de 100kmh.
- Toca som ao adicionar/diminuir quedas.
- Aplica desequilibrio paulatinamente entre 0-100s.
- Exibe a soma bruta no placar.
- Limita pontuacao a 300 pontos (equivalente a 100kmh).

v4.2 (dez/21)
-------------

- Mostra o percentual de desequilíbrio.
- Permite voltar bola mesmo após término do jogo.
- Conta golpes manuais no modo radar sempre com a velocidade 30km/h.

v4.1 (nov/21)
-------------

- Fundo vermelho para atleta que está atrás (e não o contrário).
- Som diferente para velocidade >100kmh.
- Corrige backspace que não funcionava na edição dos nomes.
- Nova aferição para evitar duplicatas.
    - Também permite configurar tempo mínimo entre golpes.
- Launcher para Linux.

v4.0 (jun/21)
-------------

- Nova regra.
- Novos sons. Faixas de 10 em 10km/h.
- v4.0.2
    - Nova configuração `RADAR_REPS` para calibre do radar.

v3.1 (ago/20)
-------------

- Suporte ao radar.
- Operação manual pelo teclado.
- Jogo de trincas.
- Máximo de 100 ataques por atleta.
- v3.1.2
    - Modo "esquenta" de aquecimento.
    - Não toca sons abaixo de 50 (mas continua exibindo).
    - Corrige CTRL-BACKSPACE.
- v3.1.3
    - Relatório geral da competição em "resultados.csv".
    - Correções no tempo de aquecimento.
    - Tempo máximo de descanso com contagem regressiva.
    - Som acima de 90 km/h.
    - Tempo passa a cada segundo.
    - Tamanho das fontes maiores.

v3.0 (jul/20)
-------------

- Regra nova com limite de golpes e velocidade mínima de ataque.
- Base: 4 minutos, 50 km/h, 120 ataques (108+12).

v2.4 (fev/20)
-------------

- Padrão de tempo é de 4:00 (era 5:00).
    - 1.5% por queda (1.2% para 5:00).
    - 20 normais (25 para 5:00).
    - 12 revés (15 para 5:00).
- Marca tempo de descanso.
- Aparelho detecta se placar está conectado.
- Acumulativo dá valores comparáveis em qualquer tempo.

v2.3 (jan/20)
-------------

- Envia configuração do aparelho para o placar.
- Move os 15% da pontuação de Revés para o Volume, caso esteja desabilitado.

v2.2 (jan/20)
-------------

- Além da pontuação média, calcula uma pontuação acumulativa.
- Não limita desconto de quedas durante o jogo, somente no fim.

v2.1 (jan/20)
-------------

- Desconto de 1% por queda (era 2%).

v2.0 (out/19)
-------------

- Regra totalmente remodelada.

v1.12 (set/19)
-------------

- A regra passa a usar o jogo de 5 minutos (300 segundos) como referência.
- O quesito de "Máximas" foi remodelado:
    - 36 golpes mais velozes: 24 normais e 12 revés (eram 11 para ambos).
    - Multiplicador de `x2` (era `x3`).
- As Máximas vêm habilitadas, mas sem o revés por padrão.
- O fator de queda passa a ser `2%` (era `1.8%`).
- O máximo de quedas passa a ser `20` (era `30`).
- Placar:
    - Exibe total de golpes.
    - Exibe e permite alterar o Juiz.

v1.11 (ago/19)
-------------

- Suporte ao modo "PC" para exibição de placar em tempo real.

v1.10 (jun/19)
-------------

- O quesito "Potência" foi renomeado para "Máximas".

v1.9 (jun/19)
-------------

- Configuração para sensibilidade da marcação dos backhands.
- A regra de potência desligada soma 0 pontos (antes assumia 50kmh para todos
  os golpes).

v1.8 (mai/19)
-------------

- A regra de potência agora considera a média dos 7 golpe mais rápidos, em vez
  de considerar cada um individualmente.
- Após a 18a queda, a apresentação é encerrada sumariamente.

v1.7 (abr/19)
-------------

- Percentual de quedas fixo em 3% para jogo de 3 minutos.
- Percentual de quedas e número de golpes de potência sempre proporcionais
  aos valores de referência para 3 minutos.
- Não há mais limite de quedas (eram 25).

v1.6
----

- O bônus de potência diminuiu de `x4` para `x3`.

v1.5
----

- CORREÇÃO: A pontuação final que vale é a que aparece em `placar` e não a de
            `relatorio`.

v1.4
----

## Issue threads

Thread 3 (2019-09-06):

Alterar regra de Máximas

fsantanna, 2019-09-06:
- 24 golpes para Normal e 12 para revés
- Habilitado por padrão
- Parâmetro "reves" para configurar a sensibilidade
  - Se for `0` significa que todos os golpes vão ser considerados como Normal
- Considerar sempre o lado maior como normal e o lado menor como revés.

Closed 2019-09-07.

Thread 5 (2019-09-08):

Maximas

eltonrios, 2019-09-08:
Quando as MAXIMAS estão desligadas, elas não pontuam e nem são mostradas, o que não ocorria antes. Apesar de não bonificar, acho um dado interessante para se apresentar.

fsantanna, 2019-09-08:
Não consegui identificar esse problema.
As máximas aparecem mesmo quando desligadas:

```
-----------------------------------------------
                 Joao / Maria
-----------------------------------------------

TOTAL ........ 19 pts
Tempo ........ 1870ms (faltam 299s)
Quedas ....... 1
Golpes ....... 2
Ritmo ........ ---
Juiz ......... Chico

-----------------------------------------------

     Joao: 17 pts
 rev  [  0  0  0  0  0  0  0  0  0  0  0  0                                     ] => 0 kmh
 nrm  [ 42  0  0  0  0  0  0  0  0  0  0  0  0  0  0  0  0  0  0  0  0  0  0  0 ] => 0 kmh

-----------------------------------------------

   Maria: 23 pts
 rev  [  0  0  0  0  0  0  0  0  0  0  0  0                                     ] => 0 kmh
 nrm  [ 48  0  0  0  0  0  0  0  0  0  0  0  0  0  0  0  0  0  0  0  0  0  0  0 ] => 0 kmh

-----------------------------------------------

(v1121/750cm/300s/max(0,85,200)/equ1/cont20/fim20)
```

fsantanna, 2019-09-08:
Agora vi que não atualiza o revés.

eltonrios, 2019-09-08:
Isso foi no placar, não no celular.

⁣Enviado por TypeApp

Em 8 de set de 2019 09:00, em 09:00, fsantanna <notifications@github.com> escreveu:
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

fsantanna, 2019-09-10:
Quando desligados, os revezes agora são exibidos no celular (sem ordenação).
No placar, aparece o vermelho e a máxima, mas o quadro "revés" permanece zerado.

Closed 2019-09-10.

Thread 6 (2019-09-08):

Erro no encerramento do tempo np PLACAR

eltonrios, 2019-09-08:
marquei 3x um mesmo jogo (5 min), sempre dá erro qd encerra o tempo... não dá o fundo vermelho, não aparece o "aguarde", e os botões ficam mudos... e permite que eu saia a bola de novo.

eltonrios, 2019-09-08:
sistematicamente, após o encerramento, o tempo retorna a 22 segundos restantes

fsantanna, 2019-09-08:
E aí, isso está resolvido?

eltonrios, 2019-09-08:
Sim, com aumento dos HITS para 650 esse erro cessou.

fsantanna, 2019-09-10:
Vou manter essa issue aberta.
A solução do `650` não é muito robusta, mas não tem muito de onde tirar memória do resto do programa.

frescogo, 2019-09-27:
O jogo é encerrado sumariamente quando chegar no limite da memória.
Como a pontuação é pela média, e não pelo acúmulo de golpes, a dupla que chegar a esse limite não será prejudicada.

Closed 2019-09-27.

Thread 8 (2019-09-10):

Informação dequem é a velocidade no celular

eltonrios, 2019-09-10:
Nessemomento de enxugar bytes, não sei se isso seria conveniente (não sei que implicação teria nesta questão), mas seria interessante se no celular também se tivesse a informação de quem é a velocidade registrada (se do atleta da ESQUERDA ou DIREITA).
Se possível, poderia ficar assim:
> saque
E 29
D 56
E 57
D 62

Ou então assim:
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

eltonrios, 2019-09-10:
Na segunda sugestão não deu para apresentar aqui, mas seria deslocar tres campos para a direita todas as velocidade do atleta à DIREITA

eltonrios, 2019-09-10:
> saque
29
   56
57
    62

Closed 2019-09-10.

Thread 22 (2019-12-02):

Incluir sets de distância (sete, sete e meio e oito metros) no PLACAR

eltonrios, 2019-12-02:
Incluir sets de distância (sete, sete e meio e oito metros) no PLACAR, com mudança atrvés de atalho CTRL+1, CRTL+2 e CTRL+3, com indicação na tela da distância selecionada.

fsantanna, 2019-12-07:
Usei apenas números 1/2/3.

Closed 2019-12-07.

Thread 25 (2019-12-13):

Distância no Placar

eltonrios, 2019-12-13:
Com a opção de três opções de distância, acessadas através de um atalho de teclado, ocorrem duas coisas:
1. Quando o placar é carregado ele traz uma interrogação na distância, quando deveria trazer a distância que estiver setada no frescogo;
2. Após usar o atalho de velocodade, a qualquer momento em que o placar estiver em primeiro plano na tela, basta teclar ENTER para editar o nome do JUIZ;

fsantanna-uerj, 2019-12-14:
2. Nem é necessário usar o atalho de velocidade.

frescogo, 2019-12-14:
2.  Nem é necessário usar o atalho de velocidade.

fsantanna-uerj, 2019-12-14:
2. Mudei para CTRL-A (Árbitro). O CTRL-J é equivalente ao ENTER (http://www.physics.udel.edu/~watson/scen103/ascii.html)

fsantanna-uerj, 2019-12-14:
1. É mais complicado. Vamos ver se essa opção de escolher a distância vai vingar.

frescogo, 2020-01-21:
resolvido na v2.3

Closed 2020-01-21.

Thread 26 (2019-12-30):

Informação equivocada no "readme"

eltonrios, 2019-12-30:
Na informação sobre CONTINUIDADE está escrito "O número limite de quedas é calculado automaticamente pelo aplicativo, dividindo-se o tempo de duração estabelecido para a apresentação por 10 (relação de 1 bola para cada 10 segundos de jogo).", entretanto o correto seria "O número limite de quedas é calculado automaticamente pelo aplicativo, dividindo-se o tempo de duração estabelecido para a apresentação por **15** (relação de 1 bola para cada **15** segundos de jogo)."

eltonrios, 2019-12-30:
Opa... desconsidere, Chico... eu estava olhando uma versão antigo do README.

Closed 2020-01-21.

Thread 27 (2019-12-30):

Informação equivocada no README #2

eltonrios, 2019-12-30:
Nas informações de CONTINUIDADE está escrito que "cada queda subtrai 3% da pontuação final da dupla", entretanto na linha 45 do software.ino está escrito "#define REF_CONT        20          // 2%".

eltonrios, 2019-12-30:
Opa... desconsidere, Chico... eu estava olhando uma versão antigo do README.

Closed 2020-01-21.

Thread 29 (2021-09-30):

O start do cronômetro, utilizando as setas, gerando velocidade

eltonrios, 2021-09-30:
O start do cronômetro, estando no modo radar, utilizando uma das setas do teclado, pode gerar velocidades espúrias vindo a interferir na pontuação do jogo.
Uma ideia seria forçar o parâmetro "máxima" para um valor de 30, por exemplo, automaticamente, bastando entrar no modo radar.

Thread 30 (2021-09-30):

Não registrar adição/remoção de quedas

eltonrios, 2021-09-30:
Estes eventos deveriam constar no relatório do jogo.

fsantanna, 2021-10-04:
Aparentemente já constam. Você chegou a testar?

eltonrios, 2021-10-09:
Ok, realmente já consta tanto a adição quanto a subtração, somente o ato de retroceder uma sequência é que não vi registro, mas também não sei se seria esmo interessante que tivesse,

Closed 2021-10-13.

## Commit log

2019-02-01 (+) TVout (>) Serial -> pserial (>) tone -> TV.tone (>) millis -> TV.millis
2019-02-05 (>) performance, pin reads
2019-02-06 (+) fzz
    [frescobol.fzz]
2019-02-25 (+) CFG button
2019-03-09 (+) fritzing
    [frescobol-nano-bt.fzz]
2019-03-11 (+) pcb
    [frescobol-mega-bt.fzz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]
2019-04-11 (>) remover info de esq/dir para pot=0
2019-06-02 Volta da regra de termino sumario por quedas.
2019-06-02 Tempo dos comandos de 5s para 3s.
2019-06-02 Explicacao para envio de relatorios.
2019-06-02 Parser para versao 1.8
2019-06-09 Adiciona configuracao de sensibilidade para os backhands.
2019-06-09 Atualiza manual para sensibilidade.
2019-07-25 Explicação da regra de "Máximas".
2019-08-15 Usa ';' como separador em vez de '\n'
2019-08-15 Completa com ';' que estavam faltando.
2019-08-16 Corrige jogador que golpeou a ultima kmh.
2019-08-16 Envia total de golpes.
2019-08-16 Envia media de velocidade.
2019-08-17 Limpa o repositorio.
    [frescobol-mega-bt.fzz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]
2019-09-06 Reorganizacao da regra de maximas.
2019-09-24 Regra de 2:30
2019-09-27 Regra de 20% do revés.
2019-09-29 Revés 10% em vez de 20%.
2020-01-04 Critério de desempate para classificação.
2020-01-20 Regra: critério de desempate.
2020-01-30 Corrige texto de desequilibrio.
2020-07-28 Corrige regra de 136 para 120 golpes.
2020-10-23 Move arquivos antigos para old/
2022-10-04 - regra de intensidade
